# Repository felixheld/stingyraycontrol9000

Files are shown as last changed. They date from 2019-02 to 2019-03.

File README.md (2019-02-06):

# stingyraycontrol9000

This device combines the WS2801 led driver chip with the constant current LED driver modules from the Meanwell LDD series to get a relatively cheap digitally controllable cascadeable constant current LED driver for powerful LEDs that can be used in art installations.

If you have the PCB version 1.0, you'll need to bridge pins 3 and 4 of U1; this bug is fixed in version 1.1. We had some WS2801 chips that didn't change their behavior when connecting the polarity select pin to ground, so beware when you use WS2801 chips bought from different vendors; we didn't test if the visually different chips from a different vendor showed the same behaviour.

Do not hot-plug the modules without verifying that the ground connection is made first; otherwise you might end up with fried WS2801 chips.

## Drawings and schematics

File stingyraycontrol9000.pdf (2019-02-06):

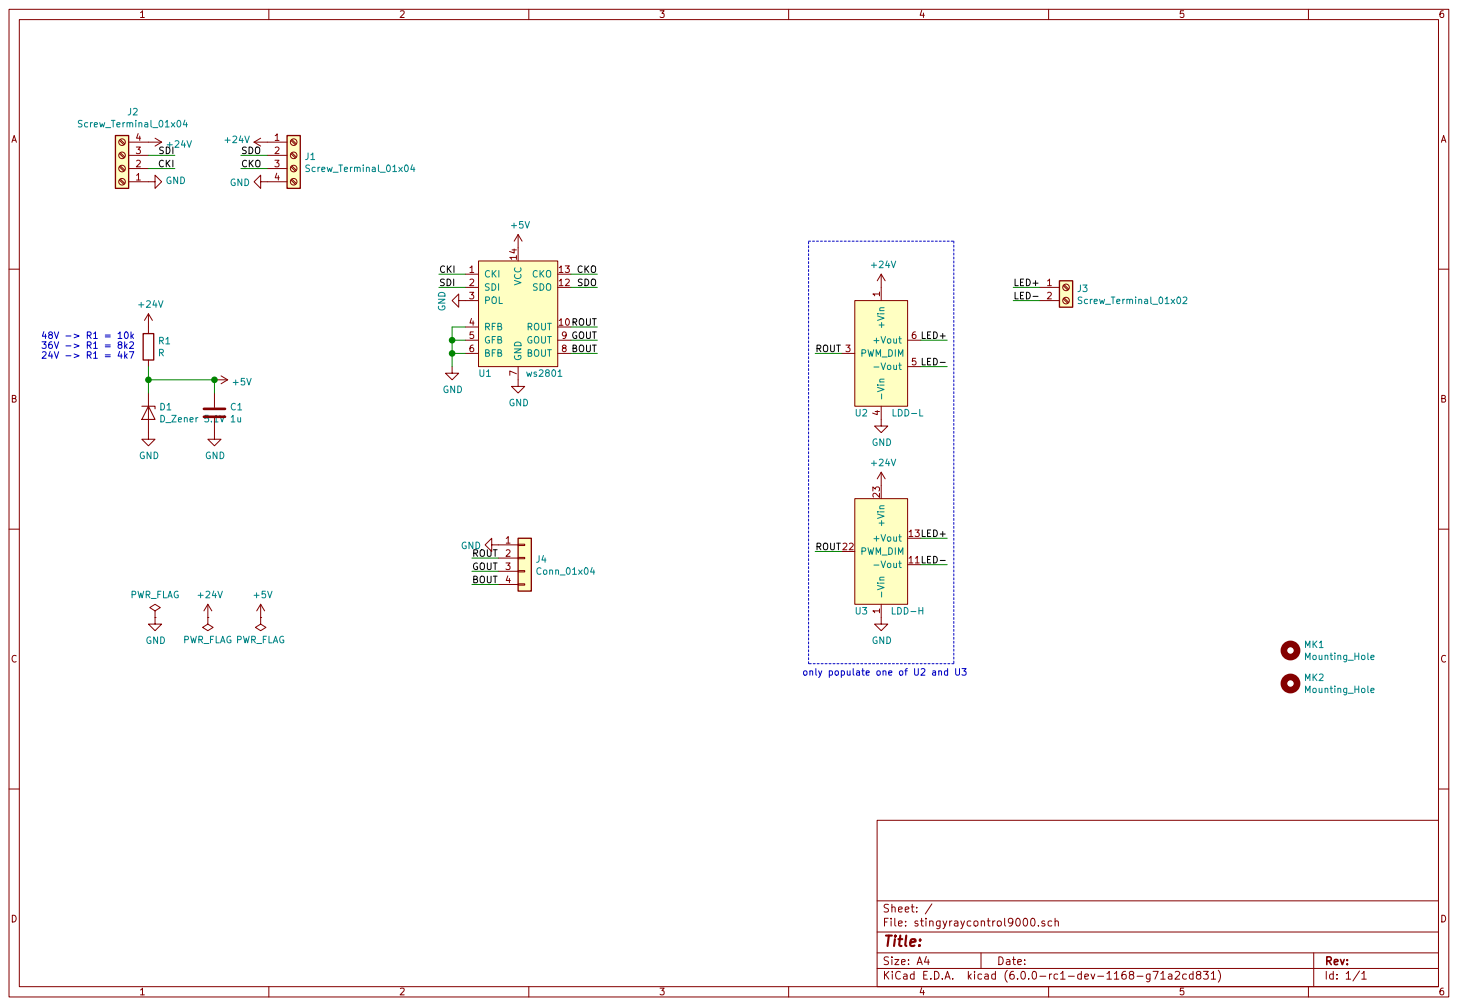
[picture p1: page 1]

7 BOUT 8 GOUT 9 U1 ws2801 GND GND

4 -Vout 5 +Vout 6 U2 LDD-L -Vin
LED- LED+

1 -Vout 11 +Vout 13 PWM_DIM 22 +Vin 23 U3 LDD-H

LED- only populate one of U2 and U3 ROUT GOUT BOUT GND

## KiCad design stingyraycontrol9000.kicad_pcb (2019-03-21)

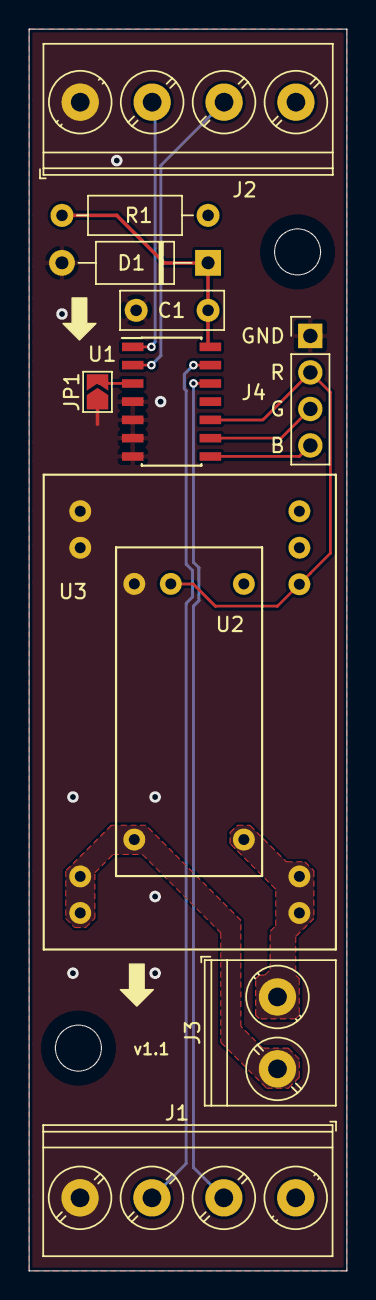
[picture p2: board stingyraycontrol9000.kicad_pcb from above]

Board: 2 copper layers, 22.1 x 86.4 mm, 13 parts (0 on the bottom side), 13 nets.

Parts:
C1: 1u; C_Rect_L7.0mm_W2.5mm_P5.00mm
D1: D_Zener 5.1V; D_A-405_P10.16mm_Horizontal
J1, J2: Screw_Terminal_01x04; TerminalBlock_Phoenix_PT-1,5-4-5.0-H_1x04_P5.00mm_Horizontal
J3: Screw_Terminal_01x02; TerminalBlock_Phoenix_PT-1,5-2-5.0-H_1x02_P5.00mm_Horizontal
J4: Conn_01x04; PinHeader_1x04_P2.54mm_Vertical
JP1: SolderJumper_2_Open; SolderJumper-2_P1.3mm_Open_TrianglePad1.0x1.5mm
MK1, MK2: Mounting_Hole; MountingHole_3.2mm_M3_ISO14580
R1: R; R_Axial_DIN0207_L6.3mm_D2.5mm_P10.16mm_Horizontal
U1: ws2801; SOIC-14_3.9x8.7mm_P1.27mm
U2: LDD-L; LDD_L
U3: LDD-H; LDD_H

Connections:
+5V: C1.1, D1.1, R1.2, U1.14
+24V: J1.1, J2.4, R1.1, U2.1, U3.23, U3.24
/BOUT: J4.4, U1.8
/CKI: J2.2, U1.1
/CKO: J1.3, U1.13
/GOUT: J4.3, U1.9
/LED+: J3.1, U2.6, U3.13, U3.14
/LED-: J3.2, U2.5, U3.11, U3.12
/ROUT: J4.2, U1.10, U2.3, U3.22
/SDI: J2.3, U1.2
/SDO: J1.2, U1.12
/polarity: JP1.2, U1.3
GND: C1.2, D1.2, J1.4, J2.1, J4.1, JP1.1, U1.4, U1.5, U1.6, U1.7, U2.4, U3.1, U3.2

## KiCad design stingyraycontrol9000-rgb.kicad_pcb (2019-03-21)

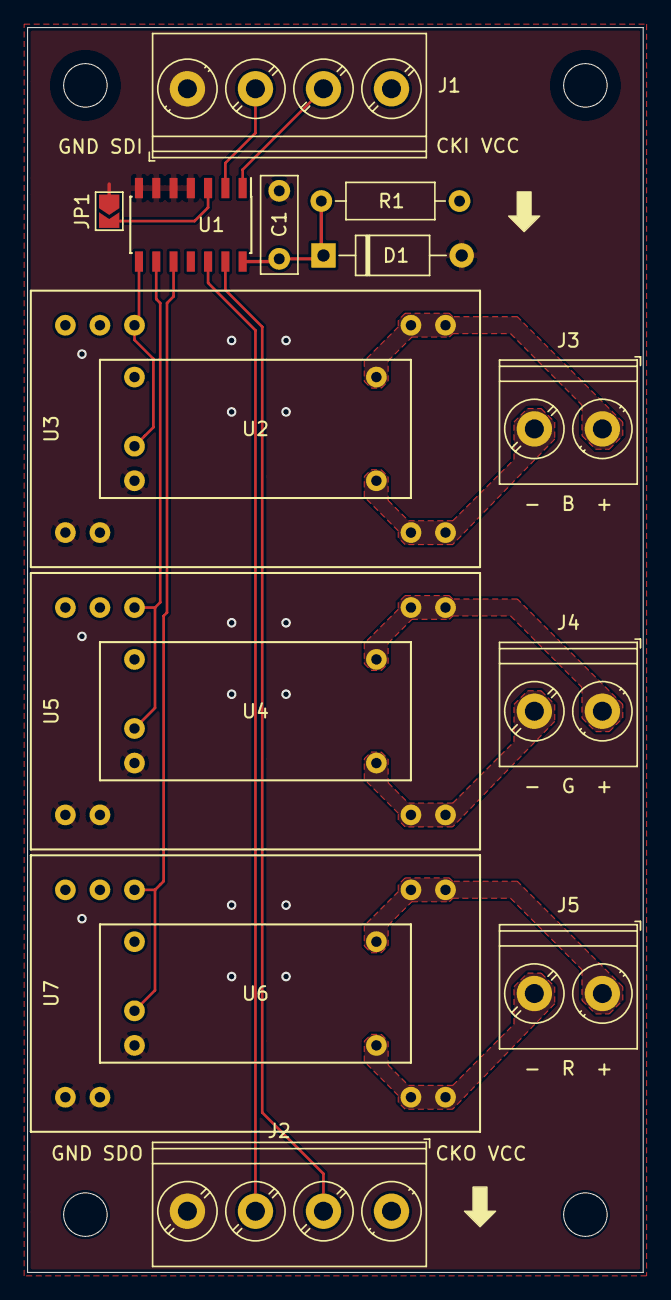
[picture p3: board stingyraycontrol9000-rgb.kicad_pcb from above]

Board: 2 copper layers, 45.2 x 91.5 mm, 20 parts (0 on the bottom side), 17 nets.

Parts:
C1: 1u; C_Rect_L7.0mm_W2.5mm_P5.00mm
D1: D_Zener 5.1V; D_A-405_P10.16mm_Horizontal
J1, J2: Screw_Terminal_01x04; TerminalBlock_Phoenix_PT-1,5-4-5.0-H_1x04_P5.00mm_Horizontal
J3, J4, J5: Screw_Terminal_01x02; TerminalBlock_Phoenix_PT-1,5-2-5.0-H_1x02_P5.00mm_Horizontal
JP1: SolderJumper_2_Open; SolderJumper-2_P1.3mm_Open_TrianglePad1.0x1.5mm
MK1, MK2, MK3, MK4: Mounting_Hole; MountingHole_3.2mm_M3_ISO14580
R1: R; R_Axial_DIN0207_L6.3mm_D2.5mm_P10.16mm_Horizontal
U1: ws2801; SOIC-14_3.9x8.7mm_P1.27mm
U2, U4, U6: LDD-L; LDD_L
U3, U5, U7: LDD-H; LDD_H

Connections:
+5V: C1.1, D1.1, R1.2, U1.14
+24V: J1.4, J2.1, R1.1, U2.1, U3.23, U3.24, U4.1, U5.23, U5.24, U6.1, U7.23, U7.24
/B: U1.8, U2.3, U3.22
/B+: J3.1, U2.6, U3.13, U3.14
/B-: J3.2, U2.5, U3.11, U3.12
/CKI: J1.3, U1.1
/CKO: J2.2, U1.13
/G: U1.9, U4.3, U5.22
/G+: J4.1, U4.6, U5.13, U5.14
/G-: J4.2, U4.5, U5.11, U5.12
/R: U1.10, U6.3, U7.22
/R+: J5.1, U6.6, U7.13, U7.14
/R-: J5.2, U6.5, U7.11, U7.12
/SDI: J1.2, U1.2
/SDO: J2.3, U1.12
/polarity: JP1.2, U1.3
GND: C1.2, D1.2, J1.1, J2.4, JP1.1, U1.4, U1.5, U1.6, U1.7, U2.4, U3.1, U3.2, U4.4, U5.1, U5.2, U6.4, U7.1, U7.2

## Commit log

2019-01-05 add symbols and schematic
    [stingyraycontrol9000.sch]
2019-01-05 add footprints for meanwell constant current led drivers
2019-01-05 add roughly placed, but not routed, pcb
    [stingyraycontrol9000.kicad_pcb]
2019-01-07 remove third mounting hole
    [stingyraycontrol9000.kicad_pcb, stingyraycontrol9000.sch]
2019-01-08 route board
    [stingyraycontrol9000.kicad_pcb, stingyraycontrol9000.sch]
2019-01-08 slight optimizations
    [stingyraycontrol9000.kicad_pcb, stingyraycontrol9000.sch]
2019-01-08 add logos to pcb
    [stingyraycontrol9000.kicad_pcb]
2019-01-08 set gerber output directory
    [stingyraycontrol9000.kicad_pcb]
2019-01-08 clean up zones and routing
    [stingyraycontrol9000.kicad_pcb]
2019-01-09 add gerber file release
    [stingyraycontrol9000.kicad_pcb]
2019-01-09 connect WS2801 polarity pin to ground and bump version to 1.1
    [stingyraycontrol9000.kicad_pcb, stingyraycontrol9000.sch]
2019-01-14 add values for R1
    [stingyraycontrol9000.sch]
2019-01-15 add resistor value for 36V power supply
    [stingyraycontrol9000.sch]
2019-02-06 add pdf file of schematics
2019-02-06 add comment about WS2801 chips ignoring the state of the polarity selection pin
2019-03-21 add stingyray9000-rgb schematics
    [stingyraycontrol9000-rgb.sch]
2019-03-21 stingyraycontrol9000-rgb: add layout
    [stingyraycontrol9000-rgb.kicad_pcb]
2019-03-21 stingyraycontrol9000: add solder jumper for polarity selection
    [stingyraycontrol9000.kicad_pcb, stingyraycontrol9000.sch]

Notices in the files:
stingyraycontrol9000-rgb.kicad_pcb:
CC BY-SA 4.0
